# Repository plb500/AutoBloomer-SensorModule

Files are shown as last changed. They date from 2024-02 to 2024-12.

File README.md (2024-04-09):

# AutoBloomer Sensor Modules

<p align="center">
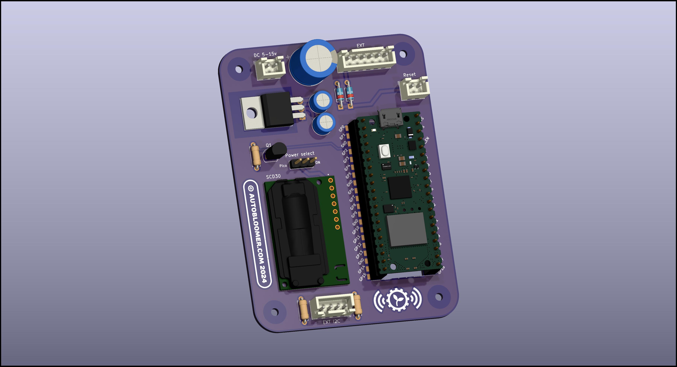
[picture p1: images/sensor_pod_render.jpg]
   
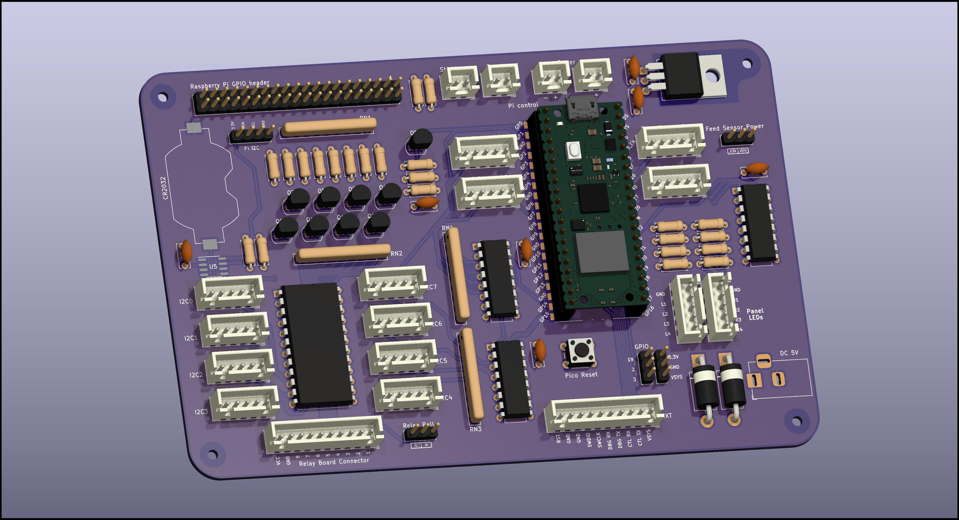
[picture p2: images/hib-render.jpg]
  
</p>

<p align="center">
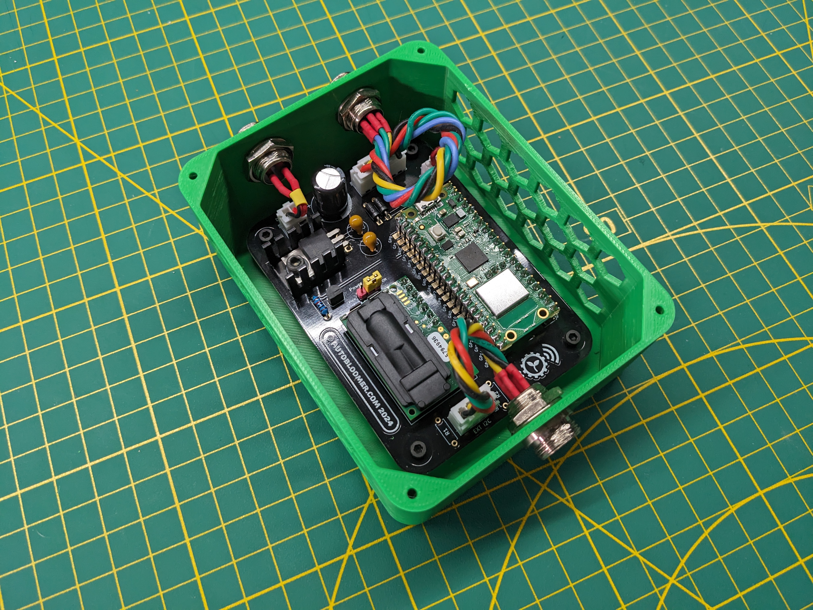
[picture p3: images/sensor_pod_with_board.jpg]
   
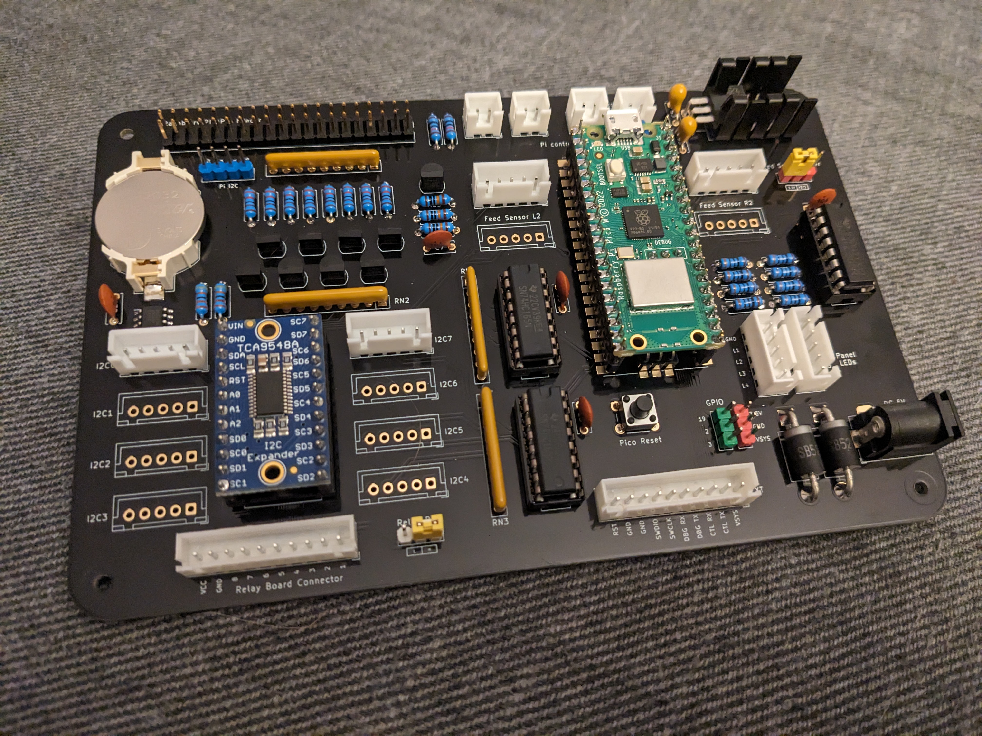
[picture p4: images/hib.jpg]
  
</p>

Full plans and code for a sensor controller capable of publishing multiple sensor data via MQTT

Raspberry Pico source code is [here](pico/src)

PCB schematics (KiCad format), plans plus any 3D prints/CNC files for the different hardware platforms are [here](hardware)

A brief overview is on [YouTube](https://youtu.be/QP_2SgASPRE)

Under the hood the sensor modules use Raspberry Pico Ws to communicate with an MQTT broker and transmit data it collates from the following sensors:
- SCD30 environmental sensor ([link](https://www.sensirion.com/products/catalog/SCD30/))
- Stemma soil sensor ([link](https://www.adafruit.com/product/4026))
- Battery voltage (for Raspberry Pi RTC) (uses an ADC pin on the Pico and custom circuitry on the HIB)
- Sonar (feed level) sensors (Currently using A02YYUW sonars - [link](https://www.dfrobot.com/product-1935.html))

I also intend to add EC and/or pH sensors to this to essentially make this a one-stop hydroponics sensor interface.

The module arranges these sensors into sensor "groups", referred to by their index. Each group effectively publishes a set of data from multiple sensors to a single MQTT topic. This allows the Sensor Pod, for example, to accumulate sensor data from both the SCD30 sensor and the Stemma Soil Sensor into a single topic, and also allows the HIB to publish sensor data to multiple topics (i.e. the RTC battery voltage and each individual connected feed sensor all publish to their own individual topics)

## Hardware platforms
Currently there are two different hardware platforms defined:
- Sensor Pod
- Hardware Interface Board (HIB)

### Sensor Pod
The Sensor Pod consists of a single sensor group providing data from the following sensors:
- Group 0
  - SCD30
    - CO2
    - Humidity
    - Temperature
  - Stemma Soil Sensor
    - Soil moisture
 
### Hardware Interface Board
The HIB consists of two distinct pieces of hardware. One section provides power and hardware control to the Raspberry Pi powering the [AutoBloomer controller](https://github.com/plb500/AutoBloomer-Controller), along with a RTC module and interfacing to relays. The other section is the sensor module which provides data from feed level sensors along with the current RTC battery module voltage. These are grouped as follows:
- Group 0
  - RTC battery level
- Group 1
  - Feed sensor
- Group 2
  - Feed sensor
 
## Module configuration
Configuration of each module is done in two ways:

### Basic module configuration
Basic pod configuration of essential runtime variables (wireless SSID/key, broker address, module location/name etc) is done via serial port connected to the bord's EXT header (3.3v, 57600/8/n/1) and transmitting commands in the format: `<COMMAND><SENSOR_GROUP><PARAMETER>` (note no space)
- SSID<< wireless ssid >> - Sets the WiFi SSID
- PASS<< password >> - Sets WiFi passkey
- NAME<< module >> - Sets sensor module name
- BRKR<< address >> - Sets the broker address
- GRPN<< sensor group index>><< sensor group name >> - Sets the name of the sensor group at the supplied index (this is used for the MQTT topic path)
- GRPL<<sensor group index>><< sensor group location >> - Sets the location of the sensor group at the supplied index (this is used for the MQTT topic path)

#### Example commands
- `SSIDMyNetwork` -> Sets the sensor module to connect to the wireless network with the SSID "MyNetwork"
- `PASSthe_key` -> Sets the sensor module to connect to the wireless network using the PSK "the_key"
- `NAMESensorModule` -> Sets the Pico's host/MQTT client name to be "SensorModule"
- `BRKRthebroker.local` -> Tells the sensor module to connect and publish to the MQTT broker with host name "thebroker.local"
- `BRKR192.168.1.50` -> Tells the sensor module to connect and publish to the MQTT broker at address "192.168.1.50"
- `GRPN0Group1Sensor` -> Sets the name of the sensor group at index 0 to "Group1Sensor"
- `GRPL0LeftChamber` -> Sets the location of the sensor group at index 0 to "LeftChamber"

Once these have been set the pod will attempt to connect to the configured broker via the supplied wireless network and begin publishing sensor data to the topic:

```
AutoBloomer/<< sensor group location >>/<< sensor group name >>
```

### Runtime sensor calibration
Once connected, the pod will also subscribe to a specific MQTT topic to listen for sensor calibration commands. The topic in question is:
```
AutoBloomer/<< sensor group location >>/<< sensor group name >>/control
```

The payload consists of a single line detailing the type of calibration to be performed. Currently the only sensor capable of (and requiring) calibration is the SCD30 on the Sensor Pod.
Calibration commands are one of the following:
- TEMP (temperature offset)
- FRC (CO2 field calibration value)

For example, setting a FRC value of 400 (i.e. recalibrating outside) and using mosquitto_pub the command line would look something like this:

```
mosquitto_pub -h broker.address -m "FRC 400" -t "AutoBloomer/SensorLocation/SensorName/control"
```

For more details on these parameters, see the SCD30 documentation [here](/docs/SCD30_Interface_Description.pdf)

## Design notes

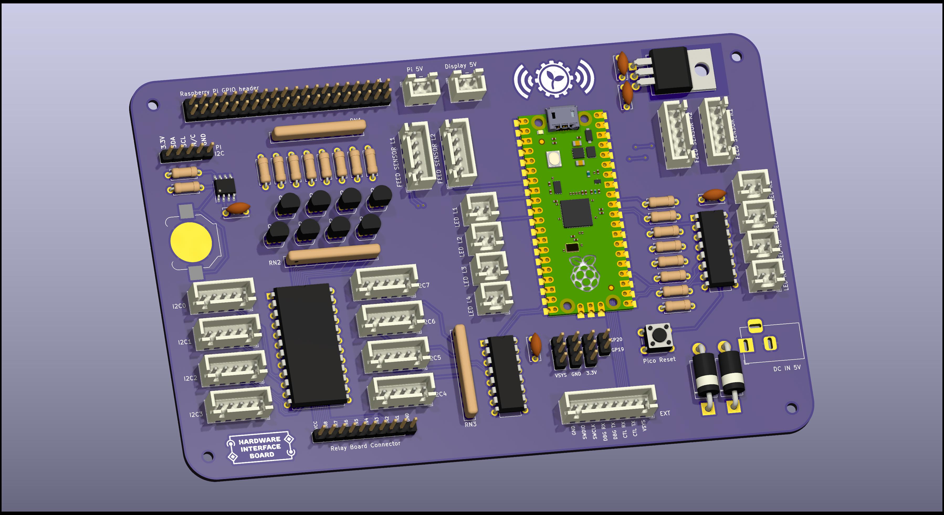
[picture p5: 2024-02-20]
hardware/HIB/PCB/gfx/SensorBoard.jpg

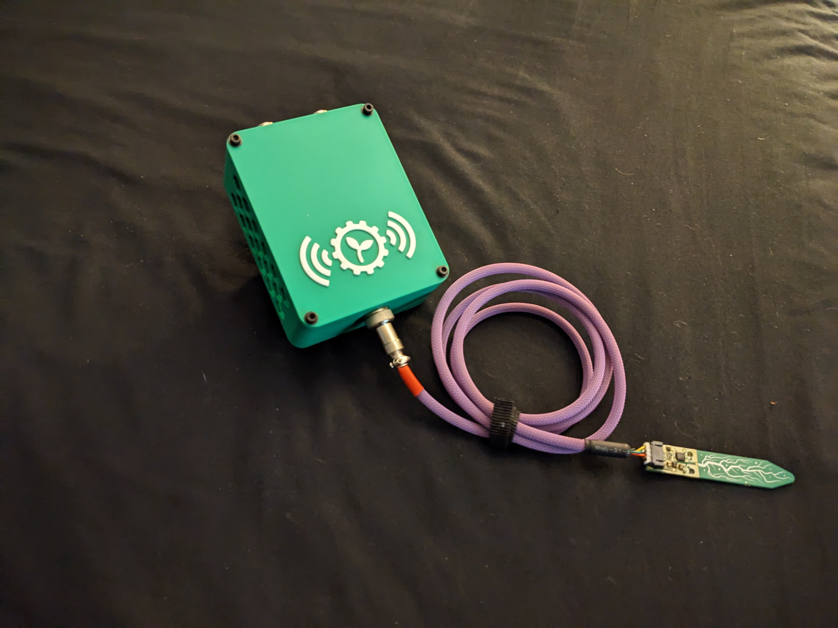
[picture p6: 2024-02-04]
images/sensor_pod_image_3.jpg

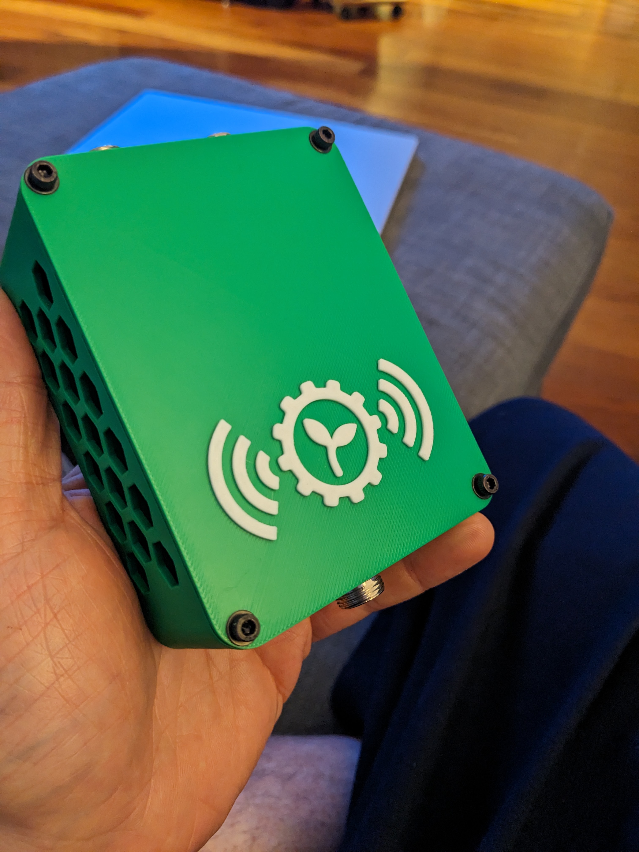
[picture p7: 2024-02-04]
images/sensor_pod_image_1.jpg

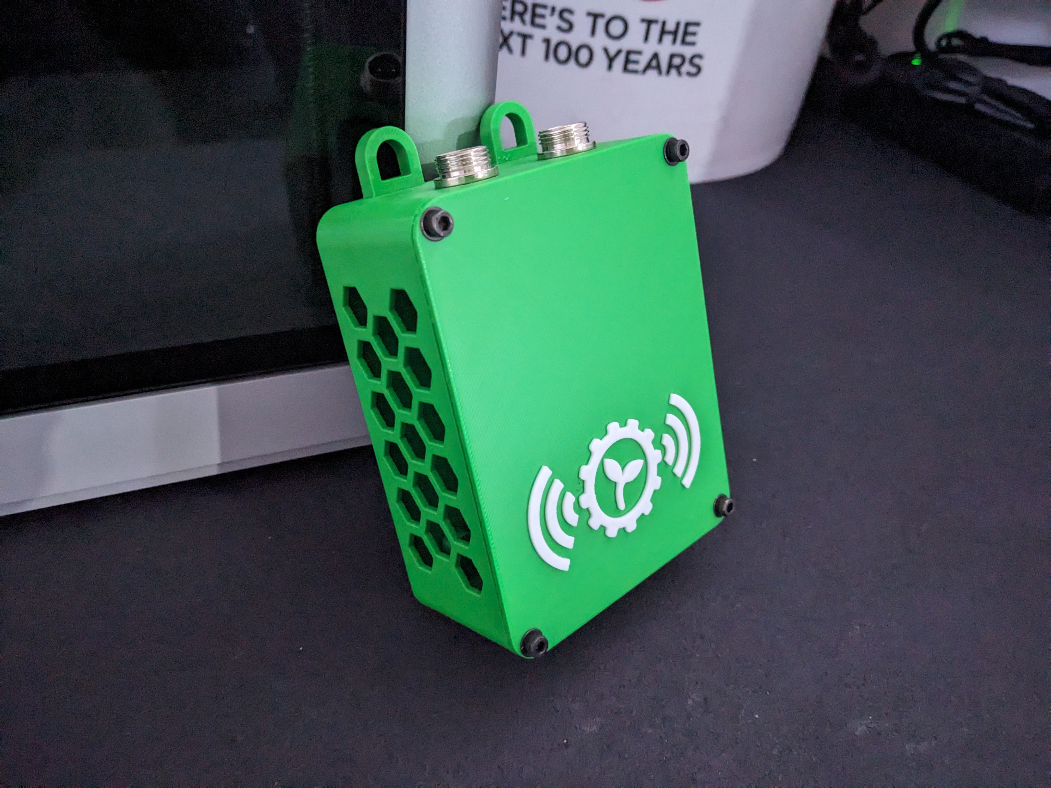
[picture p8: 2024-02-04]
images/sensor_pod_image_2.jpg

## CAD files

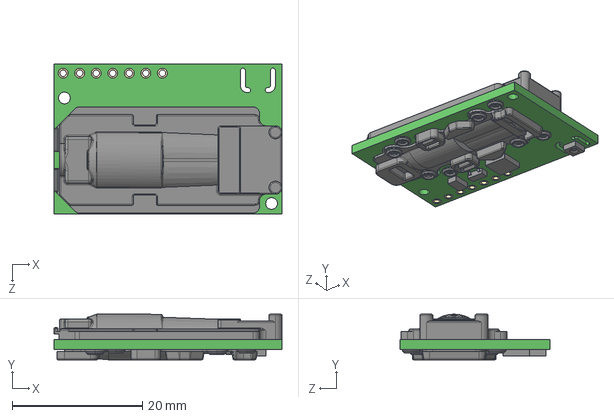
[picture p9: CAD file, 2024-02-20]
hardware/KiCad/SCD30/SCD30.step
35.0 x 7.00 x 23.0 mm

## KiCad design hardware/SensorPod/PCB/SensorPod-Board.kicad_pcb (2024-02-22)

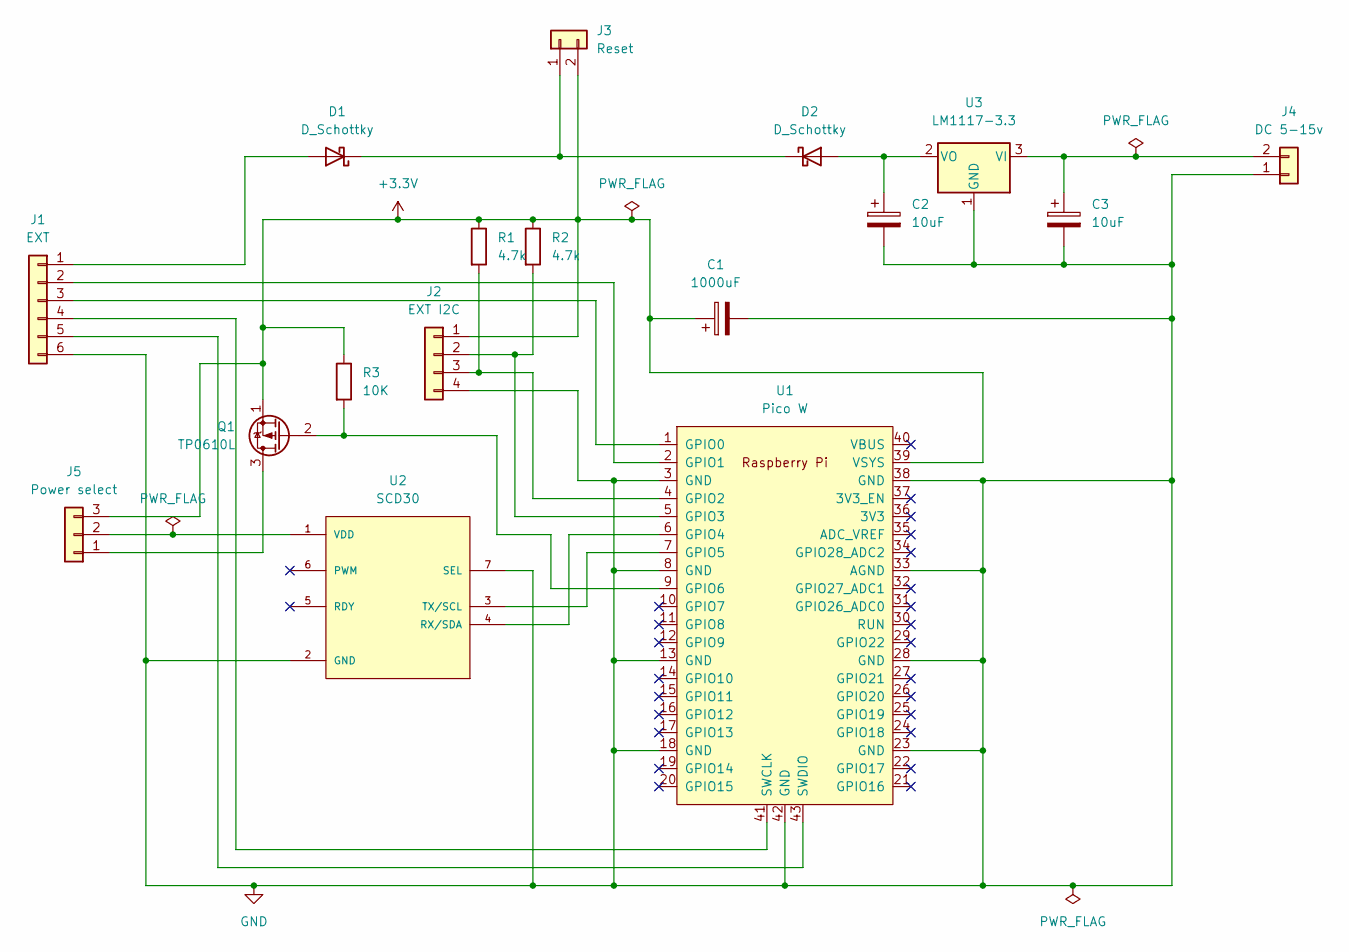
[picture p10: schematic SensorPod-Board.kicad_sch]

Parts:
C1: 1000uF; CP_Radial_D12.5mm_P5.00mm
C2, C3: 10uF; C_Radial_D6.3mm_H5.0mm_P2.50mm
D1, D2: D_Schottky; D_DO-35_SOD27_P7.62mm_Horizontal
J1: EXT; JST_XH_B6B-XH-A_1x06_P2.50mm_Vertical
J2: EXT I2C; JST_XH_B4B-XH-A_1x04_P2.50mm_Vertical
J3: Reset; JST_XH_B2B-XH-A_1x02_P2.50mm_Vertical
J4: DC 5-15v; JST_XH_B2B-XH-A_1x02_P2.50mm_Vertical
J5: Power select; PinHeader_1x03_P2.54mm_Vertical
Q1: TP0610L; TO-92L_Inline
R1, R2: 4.7k; R_Axial_DIN0207_L6.3mm_D2.5mm_P7.62mm_Horizontal
R3: 10K; R_Axial_DIN0207_L6.3mm_D2.5mm_P7.62mm_Horizontal
U1: Pico W; RPi_Pico_SMD_TH
U2: SCD30; MODULE_SCD30; PARTREV D1
U3: LM1117-3.3; TO-220-3_Horizontal_TabDown

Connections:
+3.3V: C1.1, J2.1, J3.2, J5.3, Q1.1 (S), R1.1, R2.1, R3.1, U1.39 (VSYS)
GND: C1.2, C2.2, C3.2, J1.6, J2.4, J4.1, U1.3 (GND), U1.8 (GND), U1.13 (GND), U1.18 (GND), U1.23 (GND), U1.28 (GND), U1.33 (AGND), U1.38 (GND), U1.42 (GND), U2.2 (GND), U2.7 (SEL), U3.1 (GND)
unnamed: C2.1, D2.2 (A), U3.2 (VO)
unnamed: C3.1, J4.2, U3.3 (VI)
unnamed: D1.1 (K), D2.1 (K), J3.1
unnamed: D1.2 (A), J1.1
unnamed: J1.2, U1.2 (GPIO1)
unnamed: J1.3, U1.1 (GPIO0)
unnamed: J1.4, U1.41 (SWCLK)
unnamed: J1.5, U1.43 (SWDIO)
unnamed: J2.2, R2.2, U1.5 (GPIO3)
unnamed: J2.3, R1.2, U1.4 (GPIO2)
unnamed: J5.1, Q1.3 (D)
unnamed: J5.2, U2.1 (VDD)
unnamed: Q1.2 (G), R3.2, U1.9 (GPIO6)
unnamed: U1.6 (GPIO4), U2.4 (RX/SDA)
unnamed: U1.7 (GPIO5), U2.3 (TX/SCL)

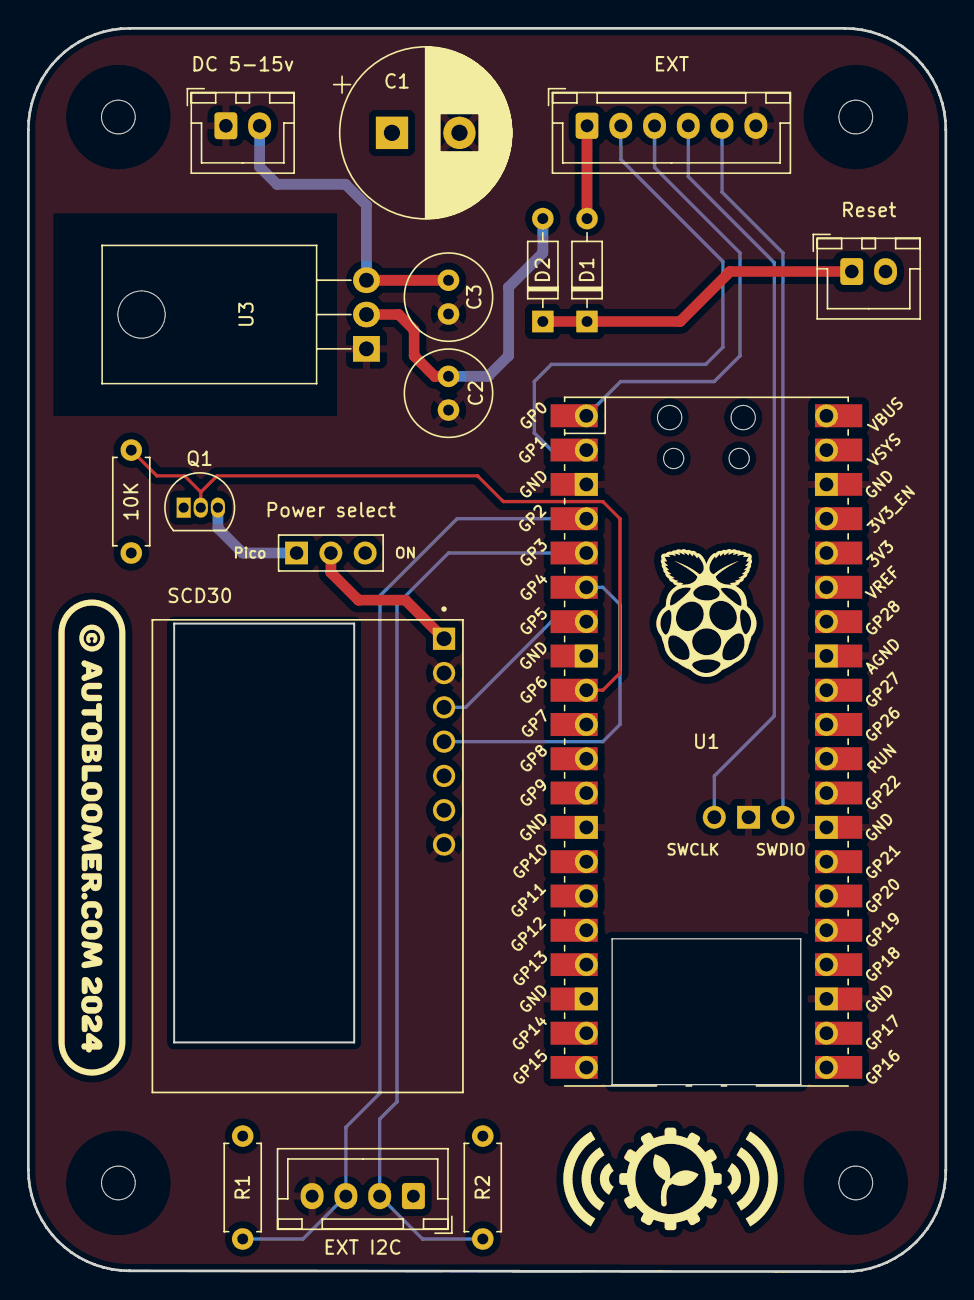
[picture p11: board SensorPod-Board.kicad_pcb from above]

Board: 2 copper layers, 67.9 x 92.1 mm, 17 parts (0 on the bottom side), 17 nets.

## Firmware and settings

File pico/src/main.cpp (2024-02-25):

#include "util/debug_io.h"
#include "messaging/multicore_mailbox.h"
#include "cores/core_0_executor.h"
#include "cores/core_1_executor.h"
#include "board_hardware/wifi_indicator.h"

#include "pico/multicore.h"


extern WiFiIndicator* _wifiIndicator;
extern vector<SensorGroup> _SENSOR_GROUPS;
MulticoreMailbox multicoreMailbox;

// Core data wrappers
Core0Executor dataCore0(
    multicoreMailbox,
    _SENSOR_GROUPS,
    _wifiIndicator
);

Core1Executor dataCore1(
    multicoreMailbox,
    _SENSOR_GROUPS
);


int main() {
    // Setup stdio
    DEBUG_PRINT_INIT()

    // Initialize cores
    dataCore0.initialize();
    Core0Executor::setExecutor(dataCore0);

    dataCore1.initialize();
    Core1Executor::setExecutor(dataCore1);

    // Run our separate cores
    multicore_launch_core1(Core1Executor::loop);
    Core0Executor::loop();

    return 1;
}

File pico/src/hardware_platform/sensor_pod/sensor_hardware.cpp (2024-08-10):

#include "sensors/sensor_group.h"
#include "pico/stdlib.h"
#include <vector>

using std::vector;

#include "board_hardware/pico_w_onboard_led_indicator.h"
#include "sensors/sensor_types/scd30_sensor.h"
#include "sensors/sensor_types/stemma_soil_sensor.h"

#define SCD30_I2C_PORT                      (i2c0)
extern const uint8_t SCD30_I2C_SDA_PIN      = 4;
extern const uint8_t SCD30_I2C_SCL_PIN      = 5;
static const uint8_t SCD30_POWER_CTL_PIN    = 6;
extern const uint SCD30_I2C_BAUDRATE        = (25 * 1000);

#define STEMMA_I2C_PORT                     (i2c1)
static const uint8_t STEMMA_I2C_SDA_PIN     = 2;
static const uint8_t STEMMA_I2C_SCL_PIN     = 3;
static const uint STEMMA_I2C_BAUDRATE       = (25 * 1000);

I2CInterface _scd30Interface = I2CInterface(
    SCD30_I2C_PORT,
    SCD30_I2C_BAUDRATE,
    SCD30_I2C_SDA_PIN,
    SCD30_I2C_SCL_PIN,
    true
);

I2CInterface _stemmaInterface = I2CInterface(
    STEMMA_I2C_PORT,
    STEMMA_I2C_BAUDRATE,
    STEMMA_I2C_SDA_PIN,
    STEMMA_I2C_SCL_PIN,
    true
);

SCD30Sensor _scd30Sensor(
    _scd30Interface,
    SCD30_POWER_CTL_PIN
);

StemmaSoilSensor _stemmaSensor(
    _stemmaInterface,
    StemmaSoilSensor::SOIL_SENSOR_1_ADDRESS
);

vector<SensorGroup> _SENSOR_GROUPS = {
    SensorGroup(
        {
            &_scd30Sensor,
            &_stemmaSensor
        }
    )
};

PicoWOnboardLEDIndicator _ledIndicator;


WiFiIndicator* _wifiIndicator = &_ledIndicator;
extern const int NUM_SENSOR_GROUPS = 2;

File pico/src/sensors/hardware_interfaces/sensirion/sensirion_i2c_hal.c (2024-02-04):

/*
 * Copyright (c) 2018, Sensirion AG
 * All rights reserved.
 *
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
 * * Neither the name of Sensirion AG nor the names of its
 *   contributors may be used to endorse or promote products derived from
 *   this software without specific prior written permission.
 *
 * THIS SOFTWARE IS PROVIDED BY THE COPYRIGHT HOLDERS AND CONTRIBUTORS "AS IS"
 * AND ANY EXPRESS OR IMPLIED WARRANTIES, INCLUDING, BUT NOT LIMITED TO, THE
 * IMPLIED WARRANTIES OF MERCHANTABILITY AND FITNESS FOR A PARTICULAR PURPOSE
 * ARE DISCLAIMED. IN NO EVENT SHALL THE COPYRIGHT HOLDER OR CONTRIBUTORS BE
 * LIABLE FOR ANY DIRECT, INDIRECT, INCIDENTAL, SPECIAL, EXEMPLARY, OR
 * CONSEQUENTIAL DAMAGES (INCLUDING, BUT NOT LIMITED TO, PROCUREMENT OF
 * SUBSTITUTE GOODS OR SERVICES; LOSS OF USE, DATA, OR PROFITS; OR BUSINESS
 * INTERRUPTION) HOWEVER CAUSED AND ON ANY THEORY OF LIABILITY, WHETHER IN
 * CONTRACT, STRICT LIABILITY, OR TORT (INCLUDING NEGLIGENCE OR OTHERWISE)
 * ARISING IN ANY WAY OUT OF THE USE OF THIS SOFTWARE, EVEN IF ADVISED OF THE
 * POSSIBILITY OF SUCH DAMAGE.
 */

#include "sensirion_i2c_hal.h"
#include "sensirion_common.h"
#include "sensirion_config.h"

// Raspberry Pico includes
#include "hardware/i2c.h"
#include "hardware/gpio.h"

/*
 * INSTRUCTIONS
 * ============
 *
 * Implement all functions where they are marked as IMPLEMENT.
 * Follow the function specification in the comments.
 */

/*
 * I2C parameters which will be used in the sensirion functions
 *
 * Values MUST be populated prior to using below functions
 * e.g. by declaring them extern and setting them:
 * 
 * extern i2c_inst_t *sensirion_i2c_inst;
 * extern int sensirion_i2c_baud;
 * extern int sensirion_sda_pin;
 * extern int sensirion_scl_pin;
 *
 * void main() {
 *     sensirion_i2c_inst = i2c1;
 *     sensirion_i2c_baud = 100 * 1000;
 *     sensirion_sda_pin = 2;
 *     sensirion_scl_pin = 3;
 * }
 * 
 */
i2c_inst_t *sensirion_i2c_inst = NULL;
int sensirion_i2c_baud = 100 * 1000;
int sensirion_sda_pin = -1;
int sensirion_scl_pin = -1;

#define SENSIRION_I2C_PARAMS_VALID  (   \
    (sensirion_i2c_inst != NULL) &&         \
    (sensirion_sda_pin != -1) &&          \
    (sensirion_scl_pin != -1)             \
)


/**
 * Select the current i2c bus by index.
 * All following i2c operations will be directed at that bus.
 *
 * THE IMPLEMENTATION IS OPTIONAL ON SINGLE-BUS SETUPS (all sensors on the same
 * bus)
 *
 * @param bus_idx   Bus index to select
 * @returns         0 on success, an error code otherwise
 */
int16_t sensirion_i2c_hal_select_bus(uint8_t bus_idx) {
    /* TODO:IMPLEMENT or leave empty if all sensors are located on one single
     * bus
     */
    return NOT_IMPLEMENTED_ERROR;
}

/**
 * Initialize all hard- and software components that are needed for the I2C
 * communication.
 */
void sensirion_i2c_hal_init(void) {
    if(!SENSIRION_I2C_PARAMS_VALID) {
        return;
    }

    i2c_init(sensirion_i2c_inst, sensirion_i2c_baud);
    gpio_set_function(sensirion_sda_pin, GPIO_FUNC_I2C);
    gpio_set_function(sensirion_scl_pin, GPIO_FUNC_I2C);

    gpio_pull_up(sensirion_sda_pin);
    gpio_pull_up(sensirion_scl_pin);
}

/**
 * Release all resources initialized by sensirion_i2c_hal_init().
 */
void sensirion_i2c_hal_free(void) {
    i2c_deinit(sensirion_i2c_inst);
}

/**
 * Execute one read transaction on the I2C bus, reading a given number of bytes.
 * If the device does not acknowledge the read command, an error shall be
 * returned.
 *
 * @param address 7-bit I2C address to read from
 * @param data    pointer to the buffer where the data is to be stored
 * @param count   number of bytes to read from I2C and store in the buffer
 * @returns 0 on success, error code otherwise
 */
int8_t sensirion_i2c_hal_read(uint8_t address, uint8_t* data, uint16_t count) {
    if(!SENSIRION_I2C_PARAMS_VALID) {
        return NOT_IMPLEMENTED_ERROR;
    }

    if(count) {
        int r = i2c_read_blocking(sensirion_i2c_inst, address, data, count, false);
        return (r > 0) ? !(r == count) : r;
    }
    return 0;
}

/**
 * Execute one write transaction on the I2C bus, sending a given number of
 * bytes. The bytes in the supplied buffer must be sent to the given address. If
 * the slave device does not acknowledge any of the bytes, an error shall be
 * returned.
 *
 * @param address 7-bit I2C address to write to
 * @param data    pointer to the buffer containing the data to write
 * @param count   number of bytes to read from the buffer and send over I2C
 * @returns 0 on success, error code otherwise
 */
int8_t sensirion_i2c_hal_write(uint8_t address, const uint8_t* data,
                               uint16_t count) {
    if(!SENSIRION_I2C_PARAMS_VALID) {
        return NOT_IMPLEMENTED_ERROR;
    }

    int r = i2c_write_blocking(sensirion_i2c_inst, address, data, count, false); 
    return (r >= 0) ? 0 : r;
}

/**
 * Sleep for a given number of microseconds. The function should delay the
 * execution for at least the given time, but may also sleep longer.
 *
 * Despite the unit, a <10 millisecond precision is sufficient.
 *
 * @param useconds the sleep time in microseconds
 */
void sensirion_i2c_hal_sleep_usec(uint32_t useconds) {
    sleep_us(useconds);
}

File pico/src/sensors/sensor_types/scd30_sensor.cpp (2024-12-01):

#include "scd30_sensor.h"
#include "sensors/hardware_interfaces/sensirion/common/scd30_i2c.h"
#include "sensors/hardware_interfaces/sensirion/common/sensirion_i2c.h"
#include "sensors/hardware_interfaces/sensirion/common/sensirion_i2c_hal.h"
#include "util/debug_io.h"

#include <cstring>

using std::make_tuple;

constexpr const char* CO2_LEVEL_JSON_KEY               = "CO2";
constexpr const char* TEMPERATURE_JSON_KEY             = "Temperature";
constexpr const char* HUMIDITY_JSON_KEY                = "Humidity";

// Sensirion SCD30 variables
extern i2c_inst_t *sensirion_i2c_inst;
extern int sensirion_i2c_baud;
extern int sensirion_sda_pin;
extern int sensirion_scl_pin;

#define SCD30_WAIT_SLEEP()    (busy_wait_us_32(10))

SCD30Sensor::SCD30Sensor(I2CInterface& i2c, uint8_t powerPin) :
    Sensor{SCD30_SENSOR, &SCD30Sensor::serializeDataToJSON},
    mI2C(i2c),
    mPowerControlPin{powerPin},
    mActive{false}
{}

void SCD30Sensor::doInitialization() {
    char serial[33];
    uint8_t firmwareMajor, firmwareMinor;

    // Setup our power control pin
    gpio_init(mPowerControlPin);
    gpio_set_dir(mPowerControlPin, GPIO_OUT);
    gpio_pull_up(mPowerControlPin);

    sleep_ms(2);

    gpio_put(mPowerControlPin, 0);

    // Initialize I2C lib
    init_driver(SCD30_I2C_ADDR_61);
    sensirion_i2c_hal_init(&mI2C);

    // See if we can get access
    while (scd30_await_data_ready()) {
        sensirion_i2c_hal_sleep_usec(1000000u);
    }

    // Validate we can communicate with the SCD30
    mActive = !scd30_read_firmware_version(&firmwareMajor, &firmwareMinor);
    DEBUG_PRINT(1, "SCD30 firmware: 0x%0X-0x%0X", firmwareMajor, firmwareMinor);

    startReadings();
}

void SCD30Sensor::reset() {
    shutdown();

    // Bounce the power to the sensor
    sleep_ms(2);
    gpio_put(mPowerControlPin, 1);
    sleep_ms(2);
    gpio_put(mPowerControlPin, 0);
    sleep_ms(2);

    initialize();
}

void SCD30Sensor::shutdown() {
    scd30_stop_periodic_measurement();
    SCD30_WAIT_SLEEP();
    sensirion_i2c_hal_free();
}           

bool SCD30Sensor::handleSensorControlCommand(SensorControlMessage& message) {
    bool consumed = false;
    
    switch(message.mCommand) {
        case SCD30_SET_TEMP_OFFSET:
            handleSetTemperatureOffsetCommand(message.mCommandParams);
            consumed = true;
            break;

        case SCD30_SET_FRC:
            handleSetFRCCommand(message.mCommandParams);
            consumed = true;
            break;

        default:
            break;
    }    

    return consumed;
}

void SCD30Sensor::setTemperatureOffset(double offset) {
    // We can only do this if we are active
    if(!mActive) {
        return;
    }

    uint16_t offsetInt = (uint16_t) (offset * 100);

    // Pause readings while we set the offset (not sure if we need to do this but it seems like a good idea)
    scd30_stop_periodic_measurement();

    DEBUG_PRINT(1, " -- Setting temperature offset to: %d", offsetInt);
    scd30_set_temperature_offset(offsetInt);

    // Restart readings
    scd30_set_measurement_interval(SCD30_MEASUREMENT_INTERVAL_SECONDS);
    scd30_start_periodic_measurement(0);
}

void SCD30Sensor::setForcedRecalibrationValue(uint16_t frc) {
    // We can only do this if we are active
    if(!mActive) {
        return;
    }

    // Pause readings while we set the offset (not sure if we need to do this but it seems like a good idea)
    scd30_stop_periodic_measurement();

    DEBUG_PRINT(1, " -- Setting FRC to: %d", frc);
    scd30_force_recalibration(frc);

    // Restart readings
    scd30_set_measurement_interval(SCD30_MEASUREMENT_INTERVAL_SECONDS);
    scd30_start_periodic_measurement(0);
}

int SCD30Sensor::serializeDataToJSON(uint8_t* data, uint8_t dataSize, char* jsonBuffer, int jsonBufferSize) {
    float co2, temp, humidity;
    memcpy(&co2, data, sizeof(float));
    data += sizeof(float);
    memcpy(&temp, data, sizeof(float));
    data += sizeof(float);
    memcpy(&humidity, data, sizeof(float));

    return snprintf(jsonBuffer, jsonBufferSize,
        "\"%s\":%.2f, \"%s\":%.2f, \"%s\":%.2f",
        CO2_LEVEL_JSON_KEY, co2,
        TEMPERATURE_JSON_KEY, temp,
        HUMIDITY_JSON_KEY, humidity
    );
}

Sensor::SensorUpdateResponse SCD30Sensor::doUpdate(absolute_time_t currentTime, uint8_t *dataStorageBuffer, size_t bufferSize) {
    Sensor::SensorUpdateResponse response = make_tuple(SENSOR_INACTIVE, 0);

    if(!mActive) {
        return response;
    }

    get<0>(response) = SENSOR_INACTIVE;

    uint16_t dataReady;
    if(!scd30_get_data_ready(&dataReady)) {
        if(dataReady) {
            float co2Reading;
            float temperatureReading;
            float humidityReading;

            if(!scd30_read_measurement_data(
                &co2Reading,
                &temperatureReading,
                &humidityReading
            )) {
                // Good data, copy it into the output buffer
                float* writePtr = reinterpret_cast<float*>(dataStorageBuffer);
                *writePtr = co2Reading;
                writePtr += 1;
                *writePtr = temperatureReading;
                writePtr += 1;
                *writePtr = humidityReading;

                get<0>(response) = SENSOR_OK;
                get<1>(response) = sizeof(float) * 3;
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

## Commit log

2023-03-15 Created wrapper struct for sensor pod
2023-03-16 Putting individual sensor (stemma/scd30) functions behind a single interface header
2024-01-19 Tidying up repo in preparation for new board
    [SensorPod-Board.kicad_pcb, SensorPod-Board.kicad_sch]
2024-01-20 Code is a bit cleaner. Need to wrap print functions still but everything is pretty functional
2024-01-21 Board fixes
    [SensorPod-Board.kicad_pcb, SensorPod-Board.kicad_sch]
2024-01-21 Switched over to using the actual Sensirion driver and providing a hal implementation. Tidied up a ton of code, fixed some weird behaviour. Better check it in before I fix everything beyond all repair
    [sensirion_i2c_hal.c]
2024-01-25 Fixing up some sensor watchdog bugs and switching to a controlled log print system
2024-01-29 Fixing up debug printing
2024-01-29 Better board version. Power cycling of sensor controlled by Pico.
    [SensorPod-Board.kicad_pcb, SensorPod-Board.kicad_sch]
2024-01-30 Setting calibration values for SCD30 via MQTT (currently disabled until I get braver)
2024-01-31 More logging. Harder resetting. Basically all I can do now with a MOSFET to physically power cycle the SCD30
2024-02-12 Converted entire codebase over to C++. (#2)
    * Mass bulk conversion of all C files to C++ classes. Haven't verified anything works yet
    * MQTT/networking/multicore SEEMS to be working
    * Sensors on core1 seem to be processing and correctly communicating to core0. MQTT transmission succeeds
    * Sensor calibration commands functional again. Everything now seems to be working in C++. Probably some horrible bugs lurking somewhere but I'll get to those later
    [main.cpp]
2024-02-18 Checkpoint commit - first steps towards full sensor inheritance hierarchy and allowing sensor groups to be compile-time defined
2024-02-18 Sensor Pod sensors (+multiple sensors in group) working
2024-02-18 Big refactor to unbind this from SensorPod implementation
2024-02-18 OK, fixed up MQTT control messages. Made the scanning mroe robust and unable to be overflowed
    [scd30_sensor.cpp]
2024-02-19 Adding more sensor types
2024-02-19 Setting name/location per sensor group (so they can each have their own topic)
2024-02-20 Fixing up SensorPod hardware config
2024-02-20 Restructuring project to include PCB/hardware designs from multiple boards (since all will be based off this repo now)
    [HardwareInterfaceBoard.kicad_sch, SCD30.step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]
2024-02-20 Tidying up SensorPod board project directory
    [SensorPod-Board-B_Cu.gbr, SensorPod-Board-B_Mask.gbr, SensorPod-Board-B_Paste.gbr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]
2024-02-22 Fixing up remaining sensors for HIB
    [battery_sensor.cpp, sensor_hardware.cpp, sonar_sensor.cpp]
2024-02-22 Fixed up paths for extra device symbols/models. Swapped HIB design over to Pico W footprint
    [HardwareInterfaceBoard.kicad_sch, SensorPod-Board.kicad_pcb, SensorPod-Board.kicad_sch]
2024-02-22 PCB renders
2024-02-22 Housekeeping - cleaning up sensor source folder structure
2024-02-22 Forgot to buil SensorPod type. Fixed.
    [sensor_hardware.cpp]
2024-02-23 Hooking in connection detect/indicate functionality for HIB
    [picoprobe.cfg, raspberrypi-swd.cfg, rp2040.cfg]
2024-02-25 Using newest pico/debugprobe code
2024-02-25 Adding onboard LED indicator wrapper for different hardware platforms
2024-03-03 Fixing MQTT JSON output and adding config for new debug probe
    [cmsis-dap.cfg]
2024-03-12 External WiFi LED indicator for HIB
2024-03-12 Fixing up some Pico bugs, new debugprobe setup
2024-03-17 Merging bitbang branch to main (#3)
    * Switching to Sensirion bitbang I2C library. At this point I'm convinced something is up with the Pico I2C lib
    * Switching to my own queue implementation with mutex. Fixing up openocd program script. Cleaning up some mess in the repo
    * Cleaning up directories and adding NOSTOP as a member to the Pico I2C wrapper (going to try going back to non-bitbang for SCD30)
    * Moving code around and consolidating sensirion interfaces to try and switch between bitbang and pic h2 I2c comms
    * Compile time configuration of underlying I2C implementation
    * CMake bug
    * Don't need the sample program
    [scd30_sensor.cpp, sensirion_pico_i2c_hal.c]
2024-03-20 Fixing some allocation and iniialization bugs. Enabling configuration of SCD30
    [scd30_sensor.cpp]
2024-08-10 Fixing up/making nicer debug output. Fixed issue with sensors not responding to MQTT control commands
    [battery_sensor.cpp, scd30_sensor.cpp, sensirion_sw_i2c.c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]
2024-12-01 Exclude KiCad auto-backups
2024-12-15 Making repo compatible with new VSCode Pico plgin and hopefully making the connectin monitoring a bit cleaner/more stable
